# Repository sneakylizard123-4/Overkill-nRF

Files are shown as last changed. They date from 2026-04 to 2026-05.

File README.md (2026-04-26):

# Overkill nRF Board

A modular RF communication board designed for the **Overkill system**, built around the **nRF24L01+ radio module** instead of a bare RF IC + Amplifier. This makes the design easier to assemble, debug, and iterate while keeping it fully modular inside the Overkill ecosystem.

---

## Overview

The Overkill nRF Board handles wireless communication for the system using **nRF24L01+ modules**.

It is designed to be:

- Easy to assemble (no RF IC routing complexity)
- Modular (plugs into Overkill ecosystem)
- Hackable (all signals exposed)
- Repairable (no fine-pitch RF ICs)
- Hand-solderable (mostly 0805 components)

### Operating Modes

- **Standalone mode** → acts like a standard nRF24 breakout module
- **Integrated mode** → RF subsystem inside Overkill system

---

## Why

- Most off-the-shelf nRF24 setups are either too barebones or too messy to integrate into real projects. Debugging is hard, power handling is often ignored, and the RF design is usually not optimized for real-world use.
- This board is designed to be a **usable, hackable, and modular RF subsystem** that can be easily integrated into the Overkill system or used standalone for RF experimentation.

---

## Key Changes from Previous Revision

- Removed discrete nRF24 RF IC design
- Switched to **nRF24L01+ module-based design**
- Simplified RF routing significantly
- Improved reliability and build speed
- Reduced RF design complexity

---

## Hardware

### Radio

- nRF24L01+ module (SPI interface)
- Optional PA+LNA module support (with proper power handling)

### Components

- Mostly **0805 footprint components**
  - Easier soldering
  - Better availability
  - More forgiving for hand assembly

### Interface

Connection to Overkill system via **JST-PH connector**:

- 3.3V power
- Data signals

---

## Design Philosophy

This board prioritizes:

- Simplicity over compact size
- Modularity over integration
- Debuggability over RF perfection

The goal is fast iteration for RF experimentation inside the Overkill platform.

---

## Power Notes

- Requires stable **3.3V supply** or **USB power** with proper regulation
- nRF24 modules are 5V tolerant, but the esp32 is not, so 3.3V is used for the logic part of the board
- Add decoupling capacitors close to module
- PA+LNA modules may require higher current bursts during transmission, so ensure power supply can handle it

---

## PCB Design Notes

- Designed around **0805 components**
- Maintain solid ground plane under RF section
- Keep antenna area free of copper and components
- use external antennas if possible for better performance

---

## Images

All pictures and screenshots should be in the `images/` folder.

### PCB Layout

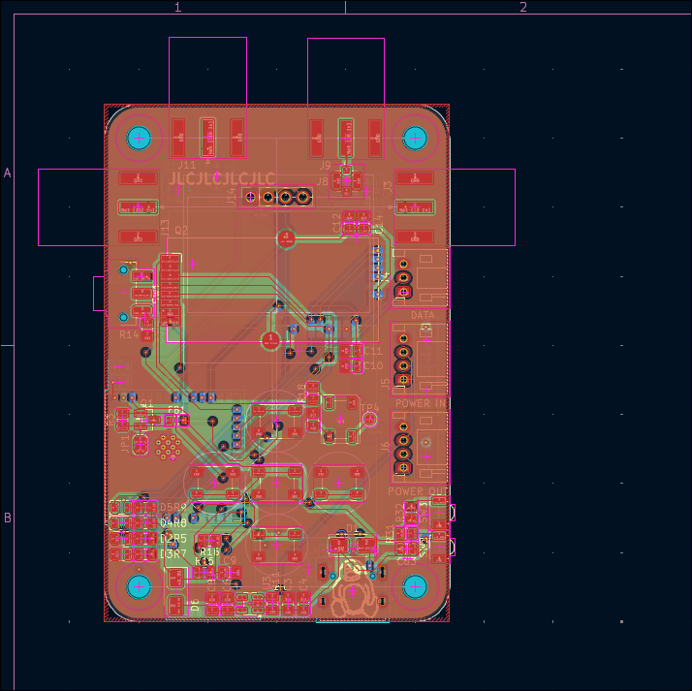
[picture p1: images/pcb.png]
PCB Layout


---

### 3D Renders

Top-side render (ray-traced KiCad):
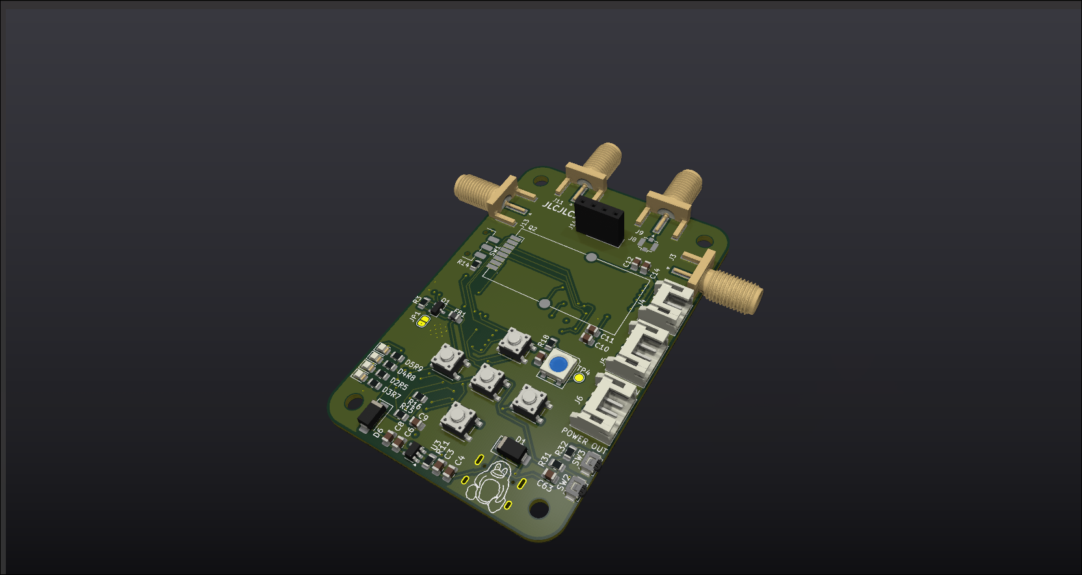
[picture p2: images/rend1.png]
Top Render


Bottom-side render (ray-traced KiCad):
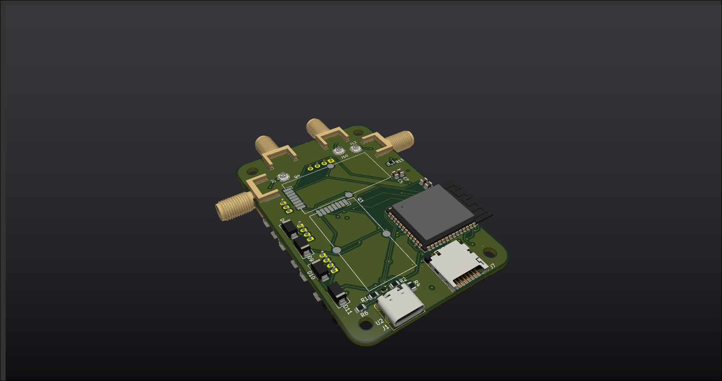
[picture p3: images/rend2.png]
Bottom Render


---

### Schematics

schematic sheet 1:
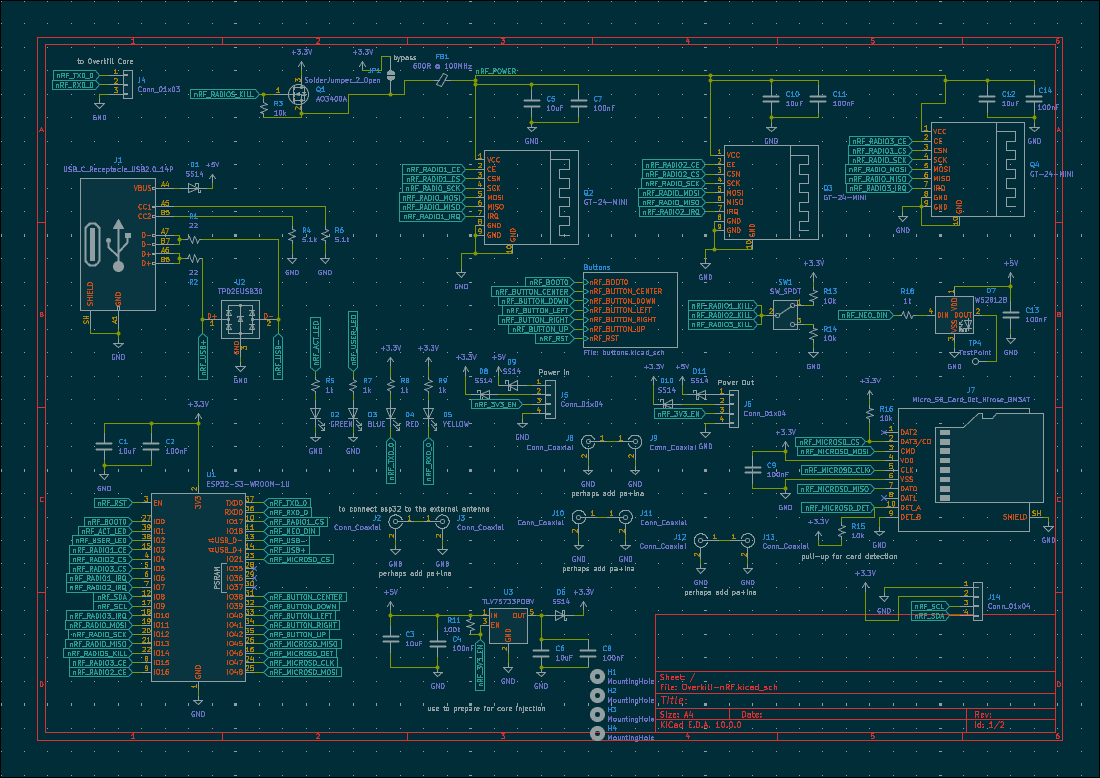
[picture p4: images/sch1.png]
Schematic 1


schematic sheet 2:
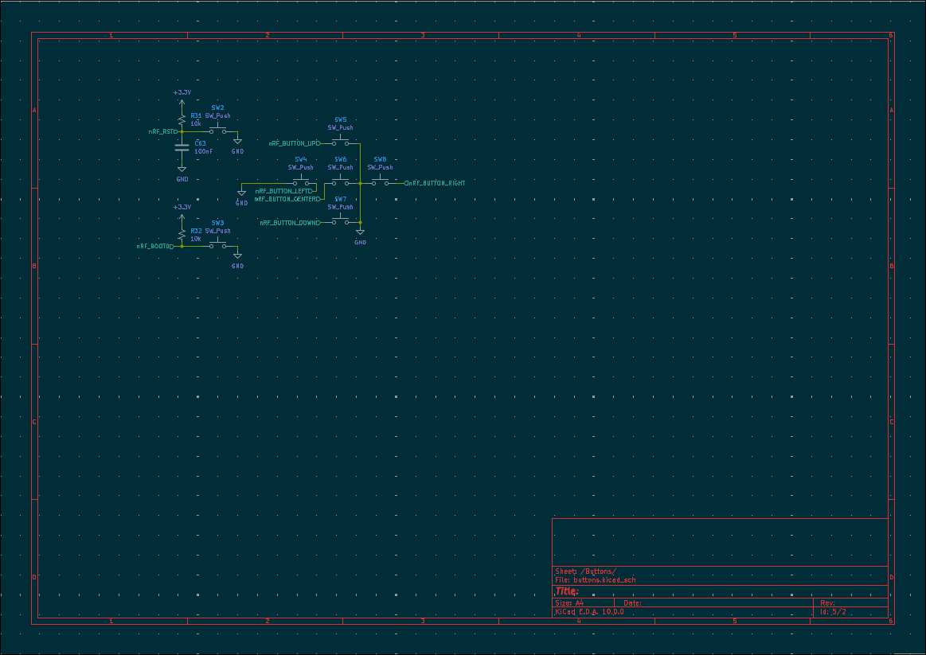
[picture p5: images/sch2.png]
Schematic 2


---

### Manufacturing / Sourcing

AliExpress cart:
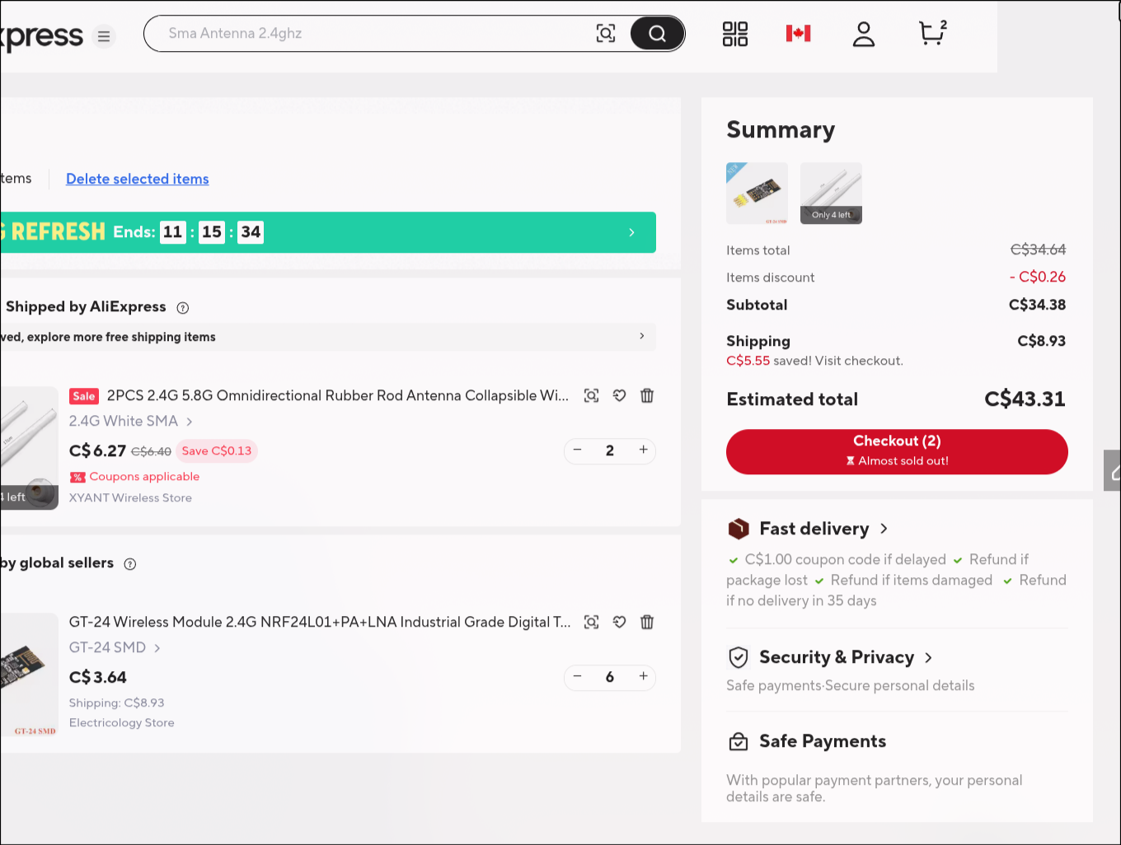
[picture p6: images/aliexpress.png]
AliExpress Cart


LCSC sourcing carts:
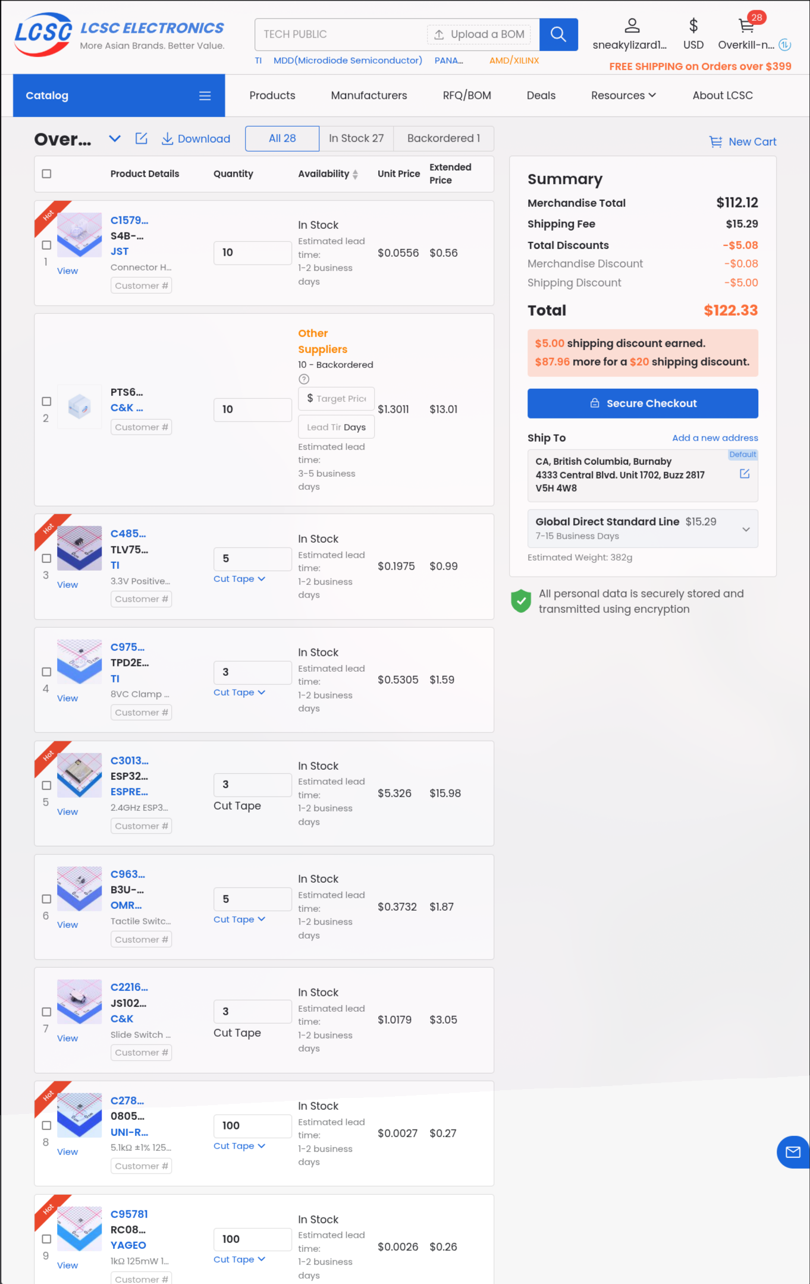
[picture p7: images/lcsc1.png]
LCSC Cart 1

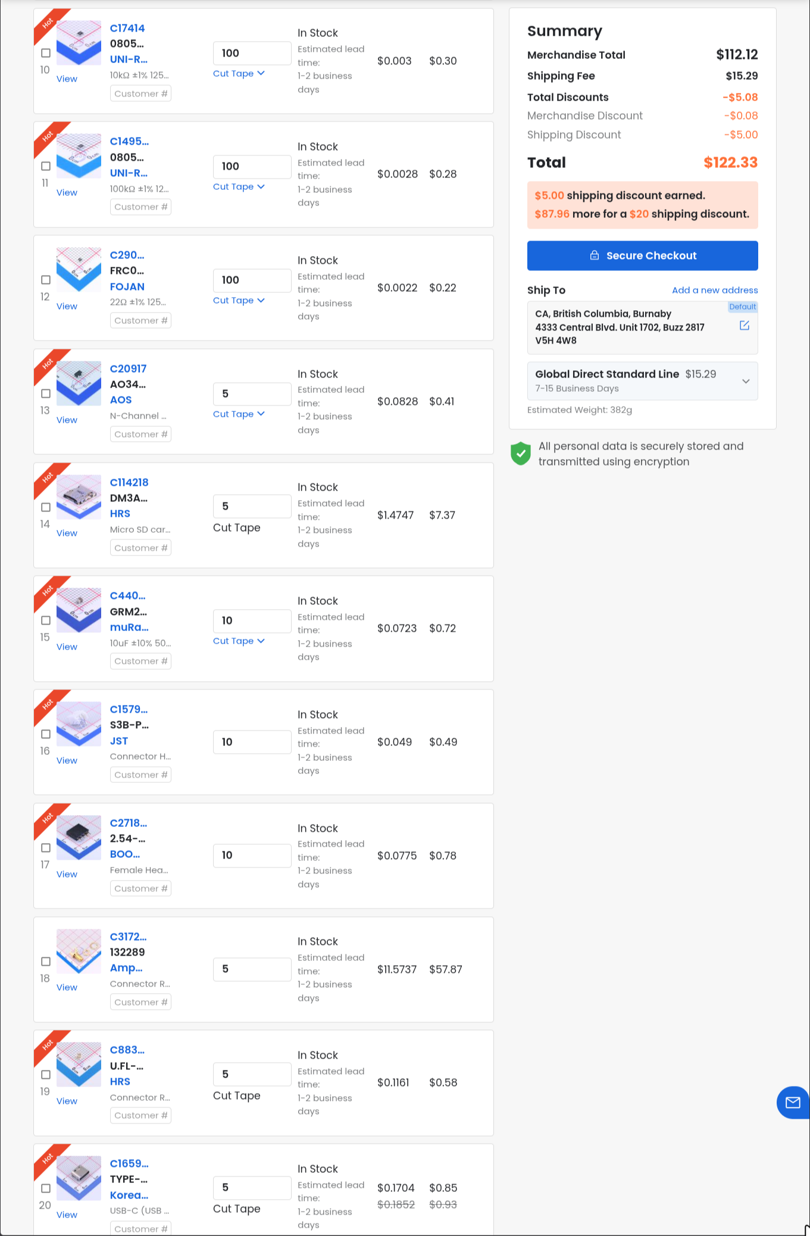
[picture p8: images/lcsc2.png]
LCSC Cart 2

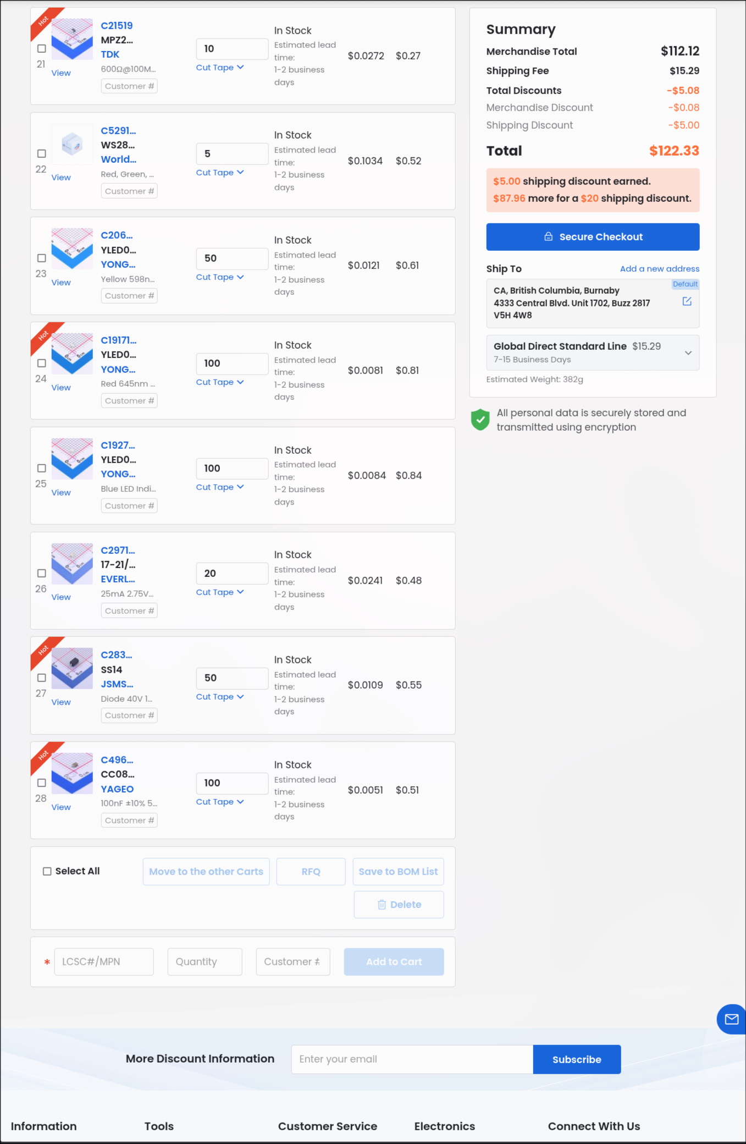
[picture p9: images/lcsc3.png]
LCSC Cart 3


JLCPCB cart:
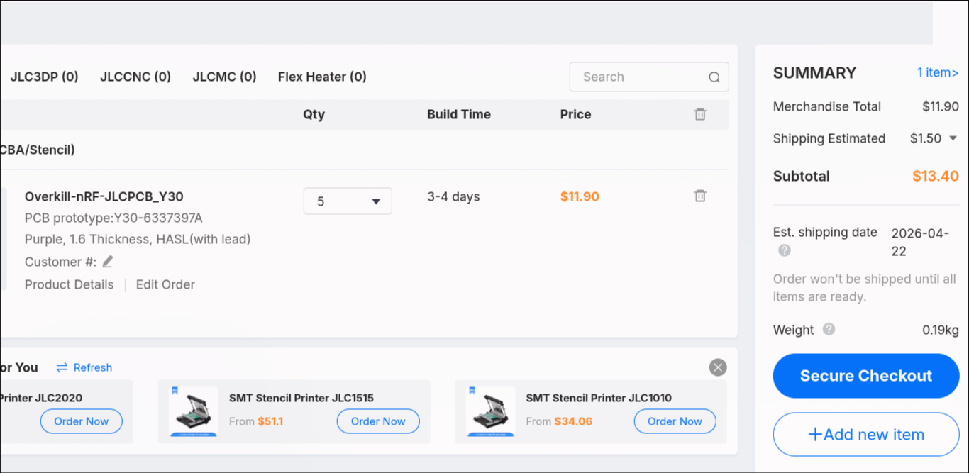
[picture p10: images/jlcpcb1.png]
JLCPCB Cart

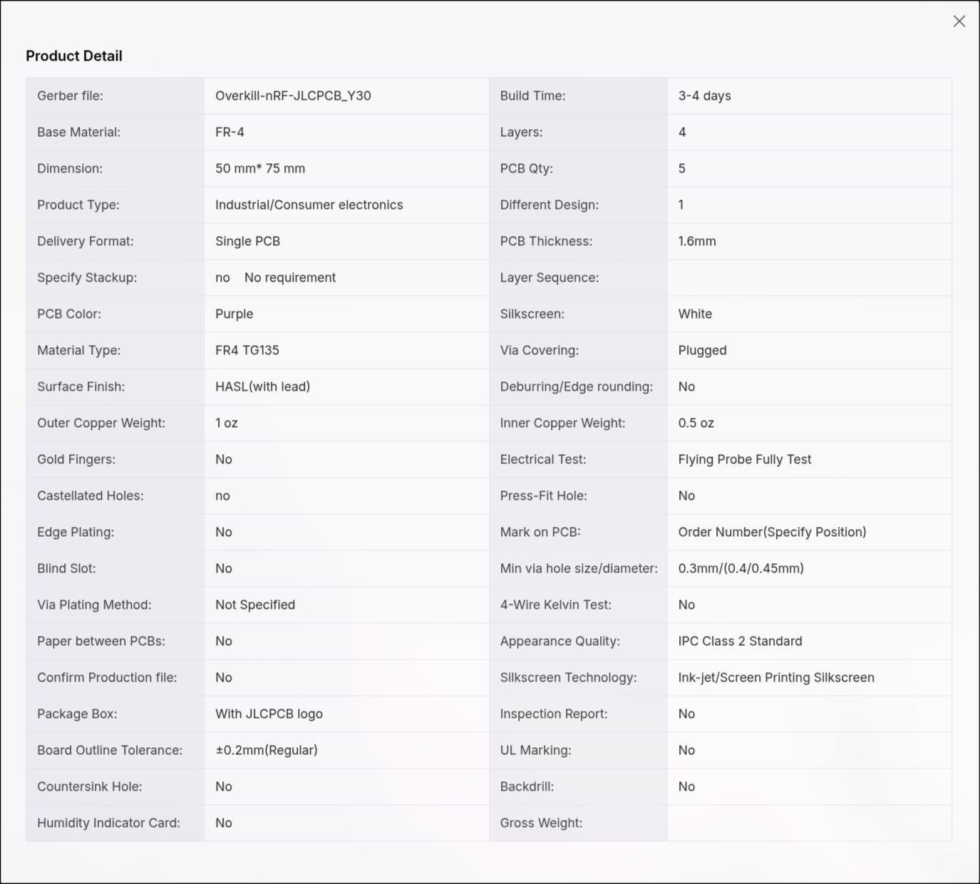
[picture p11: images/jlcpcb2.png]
JLCPCB Specs

or maybe PCBWay if they sponsor this project too!

---

### Zine Page
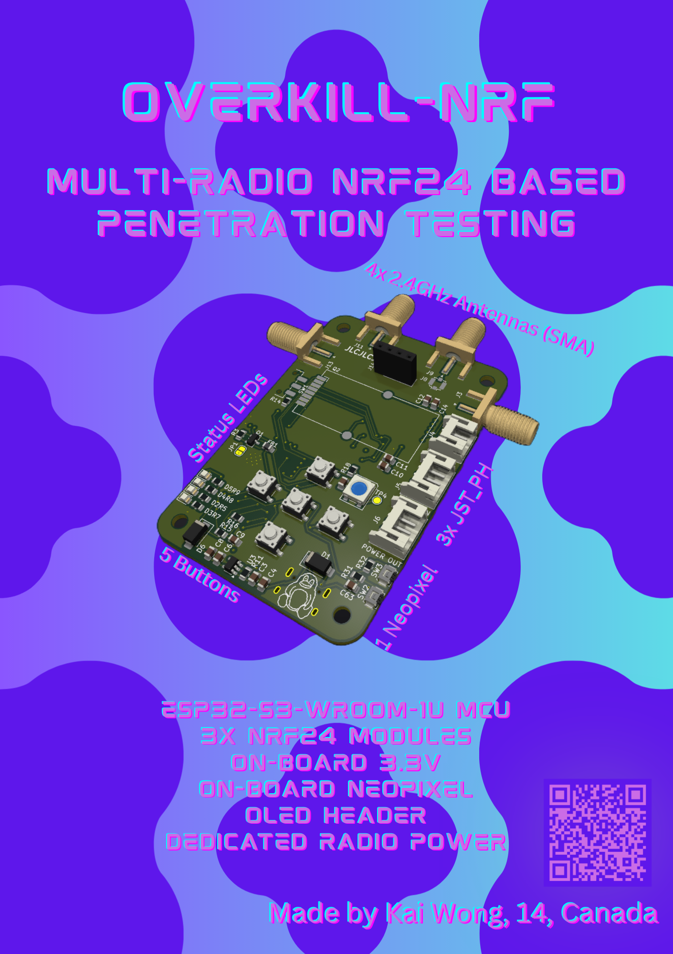
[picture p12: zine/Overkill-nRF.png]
Zine Page


## System Integration

The board connects into the Overkill system via JST-PH and is designed to interface with:

- Core controller board (SPI master)
- Power distribution board
- Other modular subsystems

Other parts of the system are being developed separately.

---

## Assembly and Programming

1. Start with passives
   - Solder resistors and capacitors first
   - Double-check values and placements
2. Power section
   - Assemble regulator and power filtering stage
   - Verify 3.3V rail before adding ICs
3. MCU and logic components
   - Solder ESP32 and other chips
   - Inspect for shorts between pins
4. nRF24 module
   - Carefully align pins
   - ensure solid ground connection
5. LEDs and indicators
   - Add status LEDs if desired
   - Match polarity correctly
   - Confirm resistor values for current limiting
6. Final inspection
   - Continuity check all power rails
   - Inspect RF sections for solder bridges

---

## How to Use

1. Powering the board
   - Connect USB power or 3.3V supply to the JST-PH connector
   - Ensure power supply can provide sufficient current for nRF24 module, especially if using PA+LNA version
2. Programming the ESP32
   - Use PlatformIO or Arduino IDE to flash firmware
   - Connect to the board via USB or UART for debugging
3. Integrating with Overkill system
   - Connect the board to the core controller via JST-PH
   - Use SPI interface to communicate with the nRF24 module
   - Test RF communication with other nRF24 devices

---

## Bill of Materials (BOM)

A full BOM is included in the repository.
see [bom.csv](bom/bom.csv) for details.

It includes:

- Component references
- Values / part numbers
- Quantities
- LCSC number
- Where to get them (AliExpress, LCSC, etc.)

---

## Repository Structure

- bom/ - Bill of Materials (BOM) files
- blender/ - 3D models and renders
- cad/ - STEP files
- firmware/ - code for project (platformio)
- images/ - pictures and screenshots
- kicad/ - KiCad project files
- zine/ - zine page for hack club

---

## Status

- Breadboard Prototype complete
- PCB routed in KiCad
- 3D assembly done
- Ready for fabrication

---

## Notes

This revision prioritizes usability and fast iteration over RF optimization complexity. The goal is to make RF experimentation inside the Overkill system fast, modular, and actually enjoyable to play with.

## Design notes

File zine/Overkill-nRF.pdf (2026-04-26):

# Overkill-nRF

## multi-radio nRF24 Based

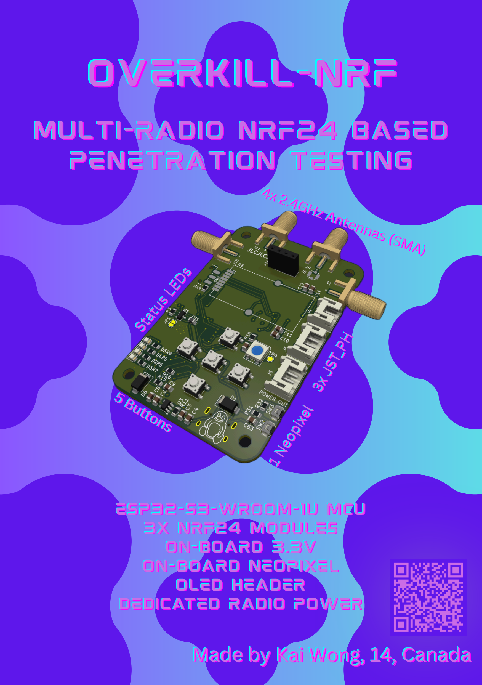
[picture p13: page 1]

ESP32-S3-WROOM-1U MCU 3x nRF24 Modules on-board 3.3v
on-board neopixel OLED header
Dedicated radio power

ESP32-S3-WROOM-1U MCU
3x nRF24 Modules
on-board 3.3v
on-board neopixel
OLED header
Dedicated radio power

## Penetration Testing

## multi-radio nRF24 Based Penetration Testing

3x JST_PH

## 4x 2.4GHz Antennas (SMA)

4x 2.

## ennas (SMA)

### Status LEDs

1 Neopixel el

## 5 Buttons

# Made by Kai Wong, 14, Canada

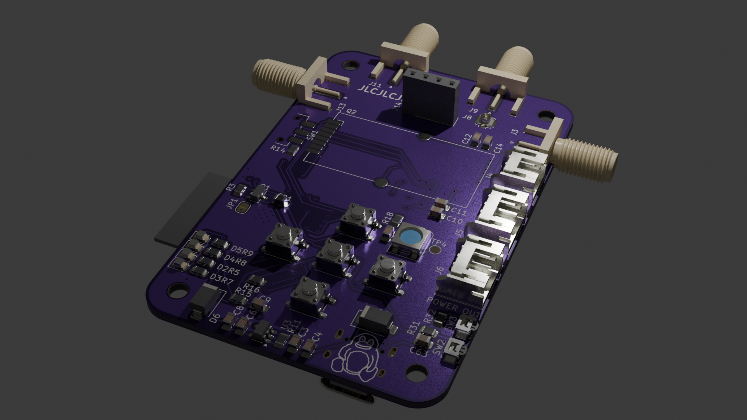
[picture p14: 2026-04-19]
blender/Purple.png

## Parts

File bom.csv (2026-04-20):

Category | Qty | Item | Description | Option/MPN | Manufacturer | Package | Unit Price | Total Price | Purchase Link
AliExpress | 2 | Antenna | 2.4GHz | 2.4 5.8G SMA | chinese | SMA connect | C$6.39 | C$12.78 | https://www.aliexpress.com/item/1005007573271319.html
AliExpress | 6 | Radio | nRF24L01+ | GT-24 SMD | nordic | SMA | C$3.64 | C$21.84 | https://www.aliexpress.com/item/4001134750735.html
AliExpress | 5 | Connector | SMA | female | amphenol | smd | C$5.91 | C$29.55 | https://www.aliexpress.com/item/1005007542020934.html
LCSC | 10 | Connector Header | 4 position 2mm Pitch | S4B-PH-K-S(LF)(SN) | JST | Through Hole Right Angle | 0.0556 | 0.56 | https://www.lcsc.com/product-detail/C157926.html
LCSC | 10 | Tactile Switch | SPST-NO 100gf | PTS647SN50SMTR2LFS | C&K | SMD | 1.3011 | 13.01 | https://www.lcsc.com/product-detail/C2799414.html
LCSC | 3 | ESD Diode | 8VC Clamp 5A | TPD2EUSB30DRTR | TI | SOT(9x3) | 0.5305 | 1.59 | https://www.lcsc.com/product-detail/C97502.html
LCSC | 3 | ESP32 Module | ESP32-S3-WROOM-1U-N16R8 | ESP32-S3-WROOM-1U-N16R8 | ESPRESSIF | SMD 19.2x18mm | 5.3260 | 15.98 | https://www.lcsc.com/product-detail/C3013946.html
LCSC | 5 | Tactile Switch | SPST 1.59N | B3U-3000P | OMRON | SMD 3x2.5mm | 0.3732 | 1.87 | https://www.lcsc.com/product-detail/C963349.html
LCSC | 3 | Slide Switch | SPDT 300mA | JS102011SAQN | C&K | SMD | 1.0179 | 3.05 | https://www.lcsc.com/product-detail/C221660.html
LCSC | 100 | Resistor | 5.1kΩ | 0805W8F5101T5E | UNI-ROYAL | 0805 | 0.0027 | 0.27 | https://www.lcsc.com/product-detail/C27834.html
LCSC | 100 | Resistor | 1kΩ | RC0805FR-071KL | YAGEO | 0805 | 0.0026 | 0.26 | https://www.lcsc.com/product-detail/C95781.html
LCSC | 100 | Resistor | 10kΩ | 0805W8F1002T5E | UNI-ROYAL | 0805 | 0.0030 | 0.30 | https://www.lcsc.com/product-detail/C17414.html
LCSC | 100 | Resistor | 100kΩ | 0805W8F1003T5E | UNI-ROYAL | 0805 | 0.0028 | 0.28 | https://www.lcsc.com/product-detail/C149504.html
LCSC | 100 | Resistor | 22Ω | FRC0805F22R0TS | FOJAN | 0805 | 0.0022 | 0.22 | https://www.lcsc.com/product-detail/C2907244.html
LCSC | 5 | MOSFET | N-Channel 30V | AO3400A | AOS | SOT-23 | 0.0828 | 0.41 | https://www.lcsc.com/product-detail/C20917.html
LCSC | 5 | Micro SD Connector | Push-Push | DM3AT-SF-PEJM5 | HRS | SMD | 1.4747 | 7.37 | https://www.lcsc.com/product-detail/C114218.html
LCSC | 10 | Capacitor | 10uF 50V | GRM21BR61H106KE43L | muRata | 0805 | 0.0723 | 0.72 | https://www.lcsc.com/product-detail/C440198.html
LCSC | 10 | Connector Header | 3 position 2mm | S3B-PH-K-S(LF)(SN) | JST | Through Hole Right Angle | 0.0490 | 0.49 | https://www.lcsc.com/product-detail/C157929.html
LCSC | 10 | Female Header | 4P 2.54mm | 2.54-1*4P | BOOMELE | Through Hole | 0.0775 | 0.78 | https://www.lcsc.com/product-detail/C2718488.html
LCSC | 5 | U.FL Connector | 50Ω | U.FL-R-SMT-1(80) | HRS | SMD | 0.1161 | 0.58 | https://www.lcsc.com/product-detail/C88374.html
LCSC | 5 | USB-C Connector | 16P | TYPE-C-31-M-12 | Hroparts | SMD | 0.1704 | 0.85 | https://www.lcsc.com/product-detail/C165948.html
LCSC | 10 | Ferrite Bead | 600Ω@100MHz | MPZ2012S601AT000 | TDK | 0805 | 0.0272 | 0.27 | https://www.lcsc.com/product-detail/C21519.html
LCSC | 5 | RGB LED | WS2812B-V6 | WS2812B-V6 | Worldsemi | SMD5050 | 0.1034 | 0.52 | https://www.lcsc.com/product-detail/C52917433.html
LCSC | 50 | LED | Yellow 598nm | YLED0805Y | YONGYUTAI | 0805 | 0.0121 | 0.61 | https://www.lcsc.com/product-detail/C20608785.html
LCSC | 100 | LED | Red 645nm | YLED0805R | YONGYUTAI | 0805 | 0.0081 | 0.81 | https://www.lcsc.com/product-detail/C19171391.html
LCSC | 100 | LED | Blue | YLED0805B | YONGYUTAI | 0805 | 0.0084 | 0.84 | https://www.lcsc.com/product-detail/C19273154.html
LCSC | 20 | LED | Green 518nm | 17-21/GHC-XS1T2M/4T | EVERLIGHT | 0805 | 0.0241 | 0.48 | https://www.lcsc.com/product-detail/C2971978.html
LCSC | 50 | Diode | 40V 1A | SS14 | JSMSEMI | SMA | 0.0109 | 0.55 | https://www.lcsc.com/product-detail/C2837270.html
LCSC | 100 | Capacitor | 100nF 50V | CC0805KRX7R9BB104 | YAGEO | 0805 | 0.0051 | 0.51 | https://www.lcsc.com/product-detail/C49678.html

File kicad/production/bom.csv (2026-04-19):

Designator | Footprint | Quantity | Value | LCSC Part #
C1, C10, C12, C3, C5, C6 | 0805 | 6 | 10uF
C11, C13, C14, C2, C4, C63, C7, C8, C9 | 0805 | 9 | 100nF
D1, D10, D11, D6, D8, D9 | D_SMA | 6 | SS14
D2 | 0805 | 1 | GREEN
D3 | 0805 | 1 | BLUE
D4 | 0805 | 1 | RED
D5 | 0805 | 1 | YELLOW
D7 | LED_WS2812B_PLCC4_5.0x5.0mm_P3.2mm | 1 | WS2812B
FB1 | 0805 | 1 | 600R @ 100MHz
J1 | USB_C_Receptacle_HRO_TYPE-C-31-M-12 | 1 | USB_C_Receptacle_USB2.0_14P
J10, J12, J2, J8 | U.FL_Molex_MCRF_73412-0110_Vertical | 4 | Conn_Coaxial
J11, J13, J3, J9 | SMA_Amphenol_132289_EdgeMount | 4 | Conn_Coaxial
J14 | PinSocket_1x04_P2.54mm_Vertical | 1 | Conn_01x04
J4 | JST_PH_S3B-PH-K_1x03_P2.00mm_Horizontal | 1 | Conn_01x03
J5, J6 | JST_PH_S4B-PH-K_1x04_P2.00mm_Horizontal | 2 | Conn_01x04
J7 | microSD_HC_Molex_104031-0811 | 1 | Micro_SD_Card_Det_Hirose_DM3AT
Q1 | SOT-23 | 1 | AO3400A
Q2, Q3, Q4 | nRF24L01-GT24_Breakout | 3 | GT-24-MINI
R1, R2 | 0805 | 2 | 22
R11 | 0805 | 1 | 100k
R13, R14, R15, R16, R3, R31, R32 | 0805 | 7 | 10k
R18, R5, R7, R8, R9 | 0805 | 5 | 1k
R4, R6 | 0805 | 2 | 5.1k
SW1 | SW_SPDT_CK_JS102011SAQN | 1 | SW_SPDT
SW2, SW3 | SW_SPST_B3U-3000P | 2 | SW_Push
SW4, SW5, SW6, SW7, SW8 | SW_SPST_PTS647_Sx38 | 5 | SW_Push
TP4 | TestPoint_Pad_D1.5mm | 1 | TestPoint
U1 | ESP32-S3-WROOM-1U | 1 | ESP32-S3-WROOM-1U
U2 | Texas_DRT-3 | 1 | TPD2EUSB30
U3 | SOT-23-5 | 1 | TLV75733PDBV

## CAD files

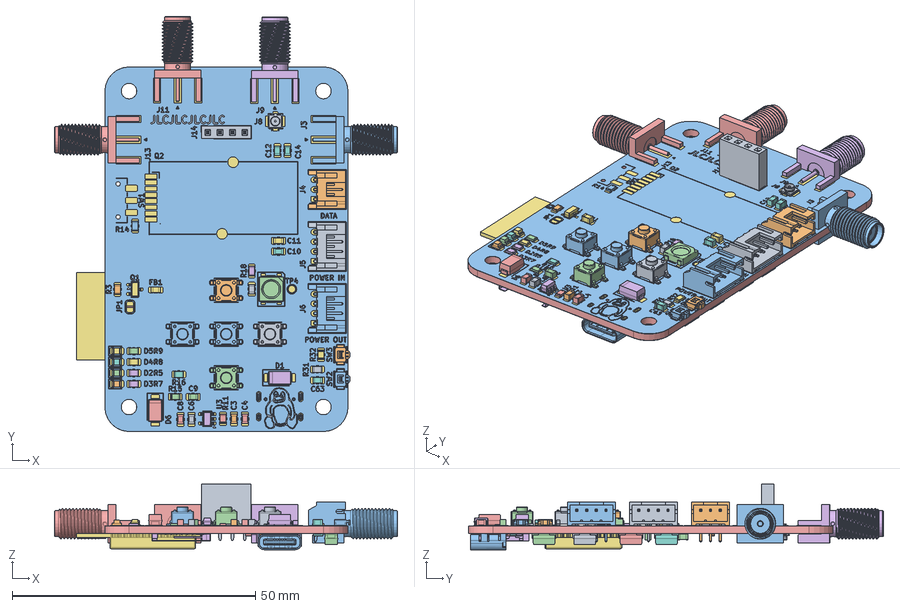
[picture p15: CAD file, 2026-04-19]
cad/Overkill-nRF.FCStd
70.6 x 85.4 x 13.5 mm
PinSocket_1x04_P2.54mm_Vertical
LED_0805_2012Metric
SMA_Amphenol_132289_EdgeMount
R_0805_2012Metric
C_0805_2012Metric
R_0805_2012Metric001
SOT-23
R_0805_2012Metric002
C_0805_2012Metric001
JST_PH_S3B-PH-K_1x03_P2.00mm_Horizontal
SW_SPST_B3U-3000P
SW_SPST_PTS647Sx38
SMA_Amphenol_132289_EdgeMount001
R_0805_2012Metric003
R_0805_2012Metric004
C_0805_2012Metric002
C_0805_2012Metric003
R_0805_2012Metric005
JST_PH_S4B-PH-K_1x04_P2.00mm_Horizontal
LED_WS2812B_PLCC4_5.0x5.0mm_P3.2mm
C_0805_2012Metric004
D_SMA
L_0805_2012Metric
C_0805_2012Metric005
U.FL_Hirose_U.FL-R-SMT-1_Vertical
SW_SPST_PTS647Sx039
SW_SPST_PTS647Sx040
C_0805_2012Metric006
D_SMA001
SOT-23-5
R_0805_2012Metric006
LED_0805_2012Metric001
R_0805_2012Metric007
SW_SPST_B3U-3000P001
SW_SPST_PTS647Sx041
LED_0805_2012Metric002
R_0805_2012Metric008
R_0805_2012Metric009
C_0805_2012Metric007
C_0805_2012Metric008
SW_SPST_PTS647Sx042
C_0805_2012Metric009
R_0805_2012Metric010
R_0805_2012Metric011
SMA_Amphenol_132289_EdgeMount002
SMA_Amphenol_132289_EdgeMount003
LED_0805_2012Metric003
C_0805_2012Metric010
JST_PH_S4B-PH-K_1x04_P2.00mm_Horizontal001
R_0805_2012Metric012
U.FL_Hirose_U.FL-R-SMT-1_Vertical001
D_SMA002
U.FL_Hirose_U.FL-R-SMT-1_Vertical002
microSD_HC_Hirose_DM3D-SF
C_0805_2012Metric011
D_SMA003
D_SMA004
Texas_DRT-3
C_0805_2012Metric012
C_0805_2012Metric013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

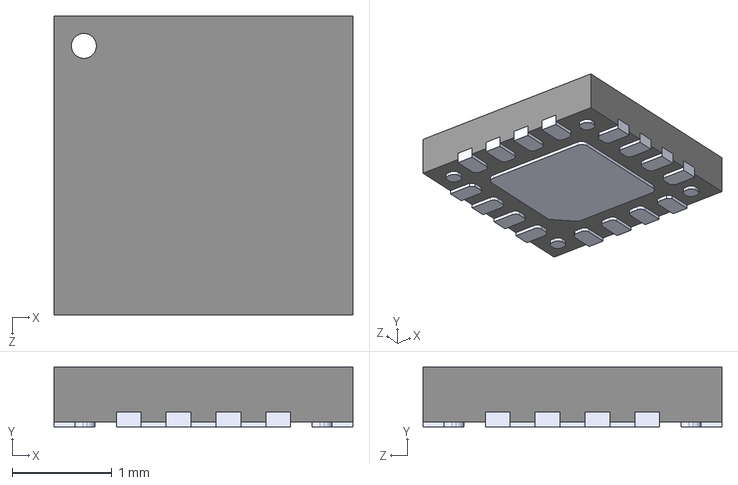
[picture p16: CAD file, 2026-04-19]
kicad/Overkill-nRF-Parts/RFX2401C/RFX2401C.step
3.00 x 0.6 x 3.00 mm

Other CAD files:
blender/Overkill-nRF.blend

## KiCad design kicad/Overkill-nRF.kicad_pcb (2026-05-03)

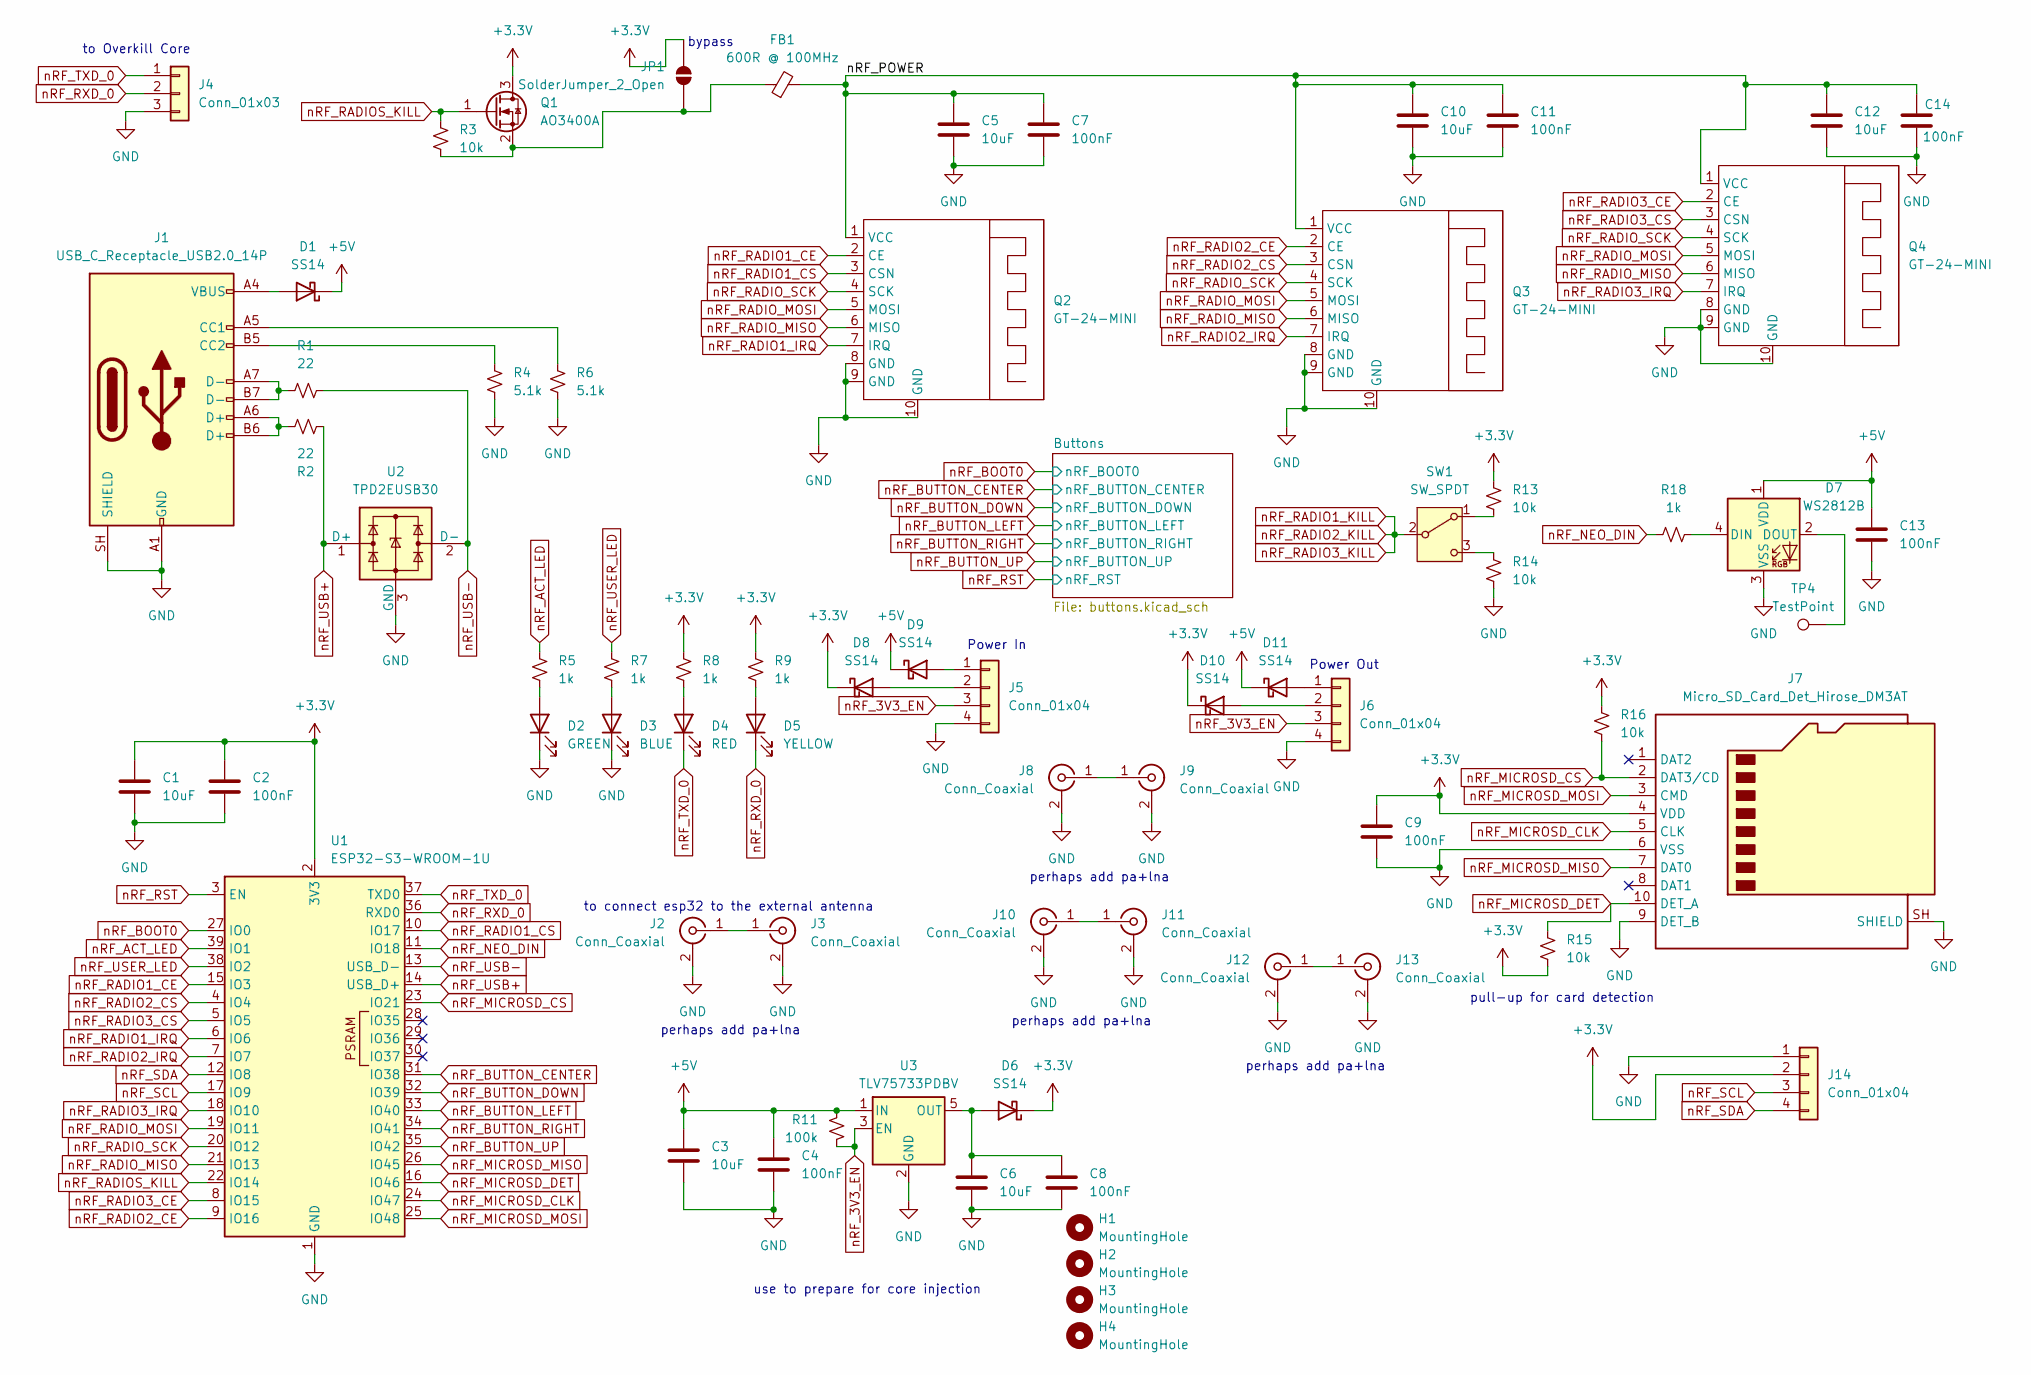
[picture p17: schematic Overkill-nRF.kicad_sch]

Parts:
C1, C3, C5, C6, C10, C12: 10uF; C_0805_2012Metric
C2, C4, C7, C8, C9, C11, C13, C14: 100nF; C_0805_2012Metric
D1, D6, D8, D9, D10, D11: SS14; D_SMA
D2: GREEN; LED_0805_2012Metric
D3: BLUE; LED_0805_2012Metric
D4: RED; LED_0805_2012Metric
D5: YELLOW; LED_0805_2012Metric
D7: WS2812B; LED_WS2812B_PLCC4_5.0x5.0mm_P3.2mm
FB1: 600R @ 100MHz; L_0805_2012Metric
H1, H2, H3, H4: MountingHole; MountingHole_3.2mm_M3
J1: USB_C_Receptacle_USB2.0_14P; USB_C_Receptacle_HRO_TYPE-C-31-M-12
J2, J8, J10, J12: Conn_Coaxial; U.FL_Molex_MCRF_73412-0110_Vertical
J3, J9, J11, J13: Conn_Coaxial; SMA_Amphenol_132289_EdgeMount
J4: Conn_01x03; JST_PH_S3B-PH-K_1x03_P2.00mm_Horizontal
J5, J6: Conn_01x04; JST_PH_S4B-PH-K_1x04_P2.00mm_Horizontal
J7: Micro_SD_Card_Det_Hirose_DM3AT; microSD_HC_Molex_104031-0811
J14: Conn_01x04; PinSocket_1x04_P2.54mm_Vertical
JP1: SolderJumper_2_Open; SolderJumper-2_P1.3mm_Open_RoundedPad1.0x1.5mm
Q1: AO3400A; SOT-23
Q2, Q3, Q4: GT-24-MINI; nRF24L01-GT24_Breakout
R1, R2: 22; R_0805_2012Metric
R3, R13, R14, R15, R16: 10k; R_0805_2012Metric
R4, R6: 5.1k; R_0805_2012Metric
R5, R7, R8, R9, R18: 1k; R_0805_2012Metric
R11: 100k; R_0805_2012Metric
SW1: SW_SPDT; SW_SPDT_CK_JS102011SAQN
TP4: TestPoint; TestPoint_Pad_D1.5mm
U1: ESP32-S3-WROOM-1U
U2: TPD2EUSB30; Texas_DRT-3
U3: TLV75733PDBV; SOT-23-5

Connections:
+3.3V: C1.1, C2.1, C9.1, D6.1 (K), D8.1 (K), D10.1 (K), J7.4 (VDD), J14.2, JP1.2 (B), Q1.3 (D), R8.1, R9.1, R13.1, R15.2, R16.1, U1.2 (3V3); also elsewhere on the board
+5V: C3.1, C4.1, C13.1, D1.1 (K), D7.1 (VDD), D9.1 (K), D11.1 (K), R11.1, U3.1 (IN)
/nRF_POWER: C5.1, C7.1, C10.1, C11.1, C12.1, C14.1, FB1.2, Q2.1 (VCC), Q3.1 (VCC), Q4.1 (VCC)
GND: C1.2, C2.2, C3.2, C4.2, C5.2, C6.2, C7.2, C8.2, C9.2, C10.2, C11.2, C12.2, C13.2, C14.2, D2.1 (K), D3.1 (K), D7.3 (VSS), J1.A1 (GND), J1.A12 (GND), J1.B1 (GND), J1.B12 (GND), J1.SH (SHIELD), J2.2 (Ext), J3.2 (Ext), J4.3, J5.4, J6.4, J7.6 (VSS), J7.9 (DET_B), J7.SH (SHIELD), J8.2 (Ext), J9.2 (Ext), J10.2 (Ext), J11.2 (Ext), J12.2 (Ext), J13.2 (Ext), J14.1, Q2.8 (GND), Q2.9 (GND), Q2.10 (GND), Q3.8 (GND), Q3.9 (GND), Q3.10 (GND), Q4.8 (GND), Q4.9 (GND), Q4.10 (GND), R4.2, R6.2, R14.2, U1.1 (GND), U1.40 (GND), U1.41 (GND), U2.3 (GND), U3.2 (GND); also elsewhere on the board
unnamed: D1.2 (A), J1.A4 (VBUS), J1.A9 (VBUS), J1.B4 (VBUS), J1.B9 (VBUS)
unnamed: D2.2 (A), R5.2
unnamed: D3.2 (A), R7.2
unnamed: D4.2 (A), R8.2
unnamed: D5.2 (A), R9.2
unnamed: C6.1, C8.1, D6.2 (A), U3.5 (OUT)
unnamed: D7.4 (DIN), R18.2
unnamed: D7.2 (DOUT), TP4.1 (1_1)
unnamed: D8.2 (A), J5.2
unnamed: D9.2 (A), J5.1
unnamed: D10.2 (A), J6.2
unnamed: D11.2 (A), J6.1
unnamed: J1.A5 (CC1), R6.1
unnamed: J1.B5 (CC2), R4.1
unnamed: J1.A6 (D+), J1.B6 (D+), R2.2
unnamed: J1.A7 (D-), J1.B7 (D-), R1.1
unnamed: J2.1 (In), J3.1 (In)
unnamed: J8.1 (In), J9.1 (In)
unnamed: J10.1 (In), J11.1 (In)
unnamed: J12.1 (In), J13.1 (In)
unnamed: FB1.1, JP1.1 (A), Q1.2 (S), R3.2
unnamed: R13.2, SW1.1 (A)
unnamed: R14.1, SW1.3 (C)
nRF_3V3_EN: J5.3, J6.3, R11.2, U3.3 (EN)
nRF_ACT_LED: R5.1, U1.39 (IO1)
nRF_BOOT0: U1.27 (IO0); also elsewhere on the board
nRF_BUTTON_CENTER: U1.31 (IO38); also elsewhere on the board
nRF_BUTTON_DOWN: U1.32 (IO39); also elsewhere on the board
nRF_BUTTON_LEFT: U1.33 (IO40); also elsewhere on the board
nRF_BUTTON_RIGHT: U1.34 (IO41); also elsewhere on the board
nRF_BUTTON_UP: U1.35 (IO42); also elsewhere on the board
nRF_MICROSD_CLK: J7.5 (CLK), U1.24 (IO47)
nRF_MICROSD_CS: J7.2 (DAT3/CD), R16.2, U1.23 (IO21)
nRF_MICROSD_DET: J7.10 (DET_A), R15.1, U1.16 (IO46)
nRF_MICROSD_MISO: J7.7 (DAT0), U1.26 (IO45)
nRF_MICROSD_MOSI: J7.3 (CMD), U1.25 (IO48)
nRF_NEO_DIN: R18.1, U1.11 (IO18)
nRF_RADIO1_CE: Q2.2 (CE), U1.15 (IO3)
nRF_RADIO1_CS: Q2.3 (CSN), U1.10 (IO17)
nRF_RADIO1_IRQ: Q2.7 (IRQ), U1.6 (IO6)
nRF_RADIO1_KILL: SW1.2 (B)
nRF_RADIO2_CE: Q3.2 (CE), U1.9 (IO16)
nRF_RADIO2_CS: Q3.3 (CSN), U1.4 (IO4)
nRF_RADIO2_IRQ: Q3.7 (IRQ), U1.7 (IO7)
nRF_RADIO3_CE: Q4.2 (CE), U1.8 (IO15)
nRF_RADIO3_CS: Q4.3 (CSN), U1.5 (IO5)
nRF_RADIO3_IRQ: Q4.7 (IRQ), U1.18 (IO10)
nRF_RADIOS_KILL: Q1.1 (G), R3.1, U1.22 (IO14)
nRF_RADIO_MISO: Q2.6 (MISO), Q3.6 (MISO), Q4.6 (MISO), U1.21 (IO13)
nRF_RADIO_MOSI: Q2.5 (MOSI), Q3.5 (MOSI), Q4.5 (MOSI), U1.19 (IO11)
nRF_RADIO_SCK: Q2.4 (SCK), Q3.4 (SCK), Q4.4 (SCK), U1.20 (IO12)
nRF_RST: U1.3 (EN); also elsewhere on the board
nRF_RXD_0: D5.1 (K), J4.2, U1.36 (RXD0)
nRF_SCL: J14.3, U1.17 (IO9)
nRF_SDA: J14.4, U1.12 (IO8)
nRF_TXD_0: D4.1 (K), J4.1, U1.37 (TXD0)
nRF_USB+: R2.1, U1.14 (USB_D+), U2.1 (D+)
nRF_USB-: R1.2, U1.13 (USB_D-), U2.2 (D-)
nRF_USER_LED: R7.1, U1.38 (IO2)

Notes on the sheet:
pull-up for card detection
perhaps add pa+lna
to connect esp32 to the external antenna
bypass
Power In
Power Out
to Overkill Core
use to prepare for core injection

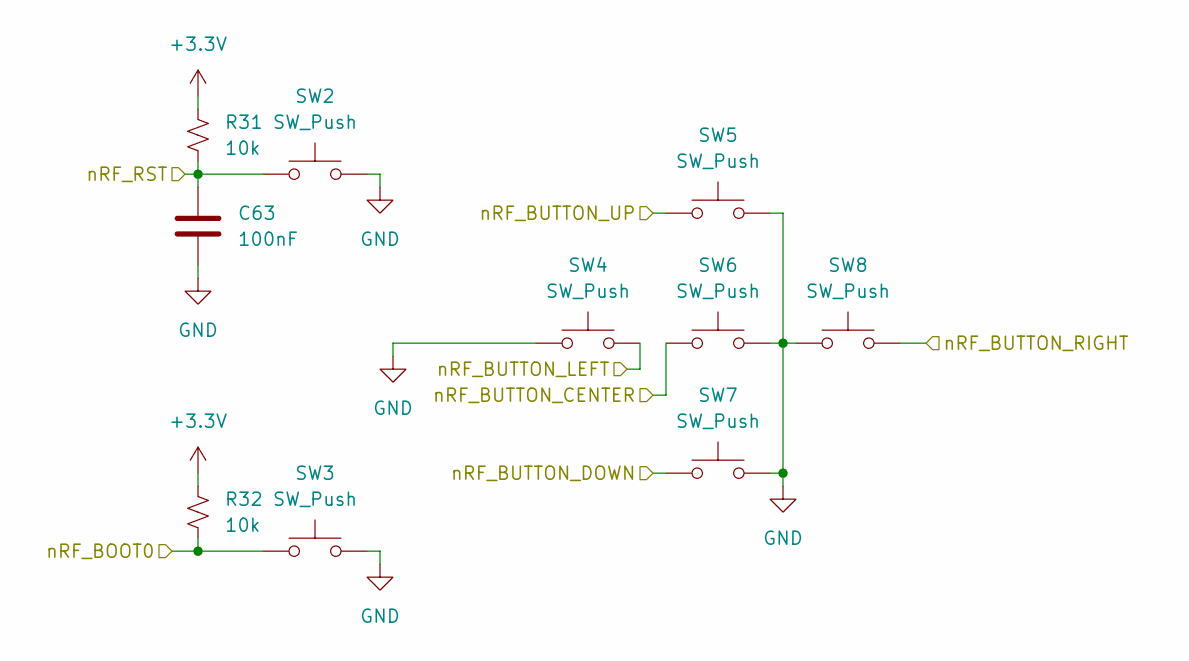
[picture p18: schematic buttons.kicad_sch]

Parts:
C63: 100nF; C_0805_2012Metric
R31, R32: 10k; R_0805_2012Metric
SW2, SW3: SW_Push; SW_SPST_B3U-3000P
SW4, SW5, SW6, SW7, SW8: SW_Push; SW_SPST_PTS647_Sx38

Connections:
+3.3V: R31.1, R32.1; also elsewhere on the board
GND: C63.2, SW2.2, SW3.2, SW4.1, SW5.2, SW6.2, SW7.2, SW8.1; also elsewhere on the board
nRF_BOOT0: R32.2, SW3.1; also elsewhere on the board
nRF_BUTTON_CENTER: SW6.1; also elsewhere on the board
nRF_BUTTON_DOWN: SW7.1; also elsewhere on the board
nRF_BUTTON_LEFT: SW4.2; also elsewhere on the board
nRF_BUTTON_RIGHT: SW8.2; also elsewhere on the board
nRF_BUTTON_UP: SW5.1; also elsewhere on the board
nRF_RST: C63.1, R31.2, SW2.1; also elsewhere on the board

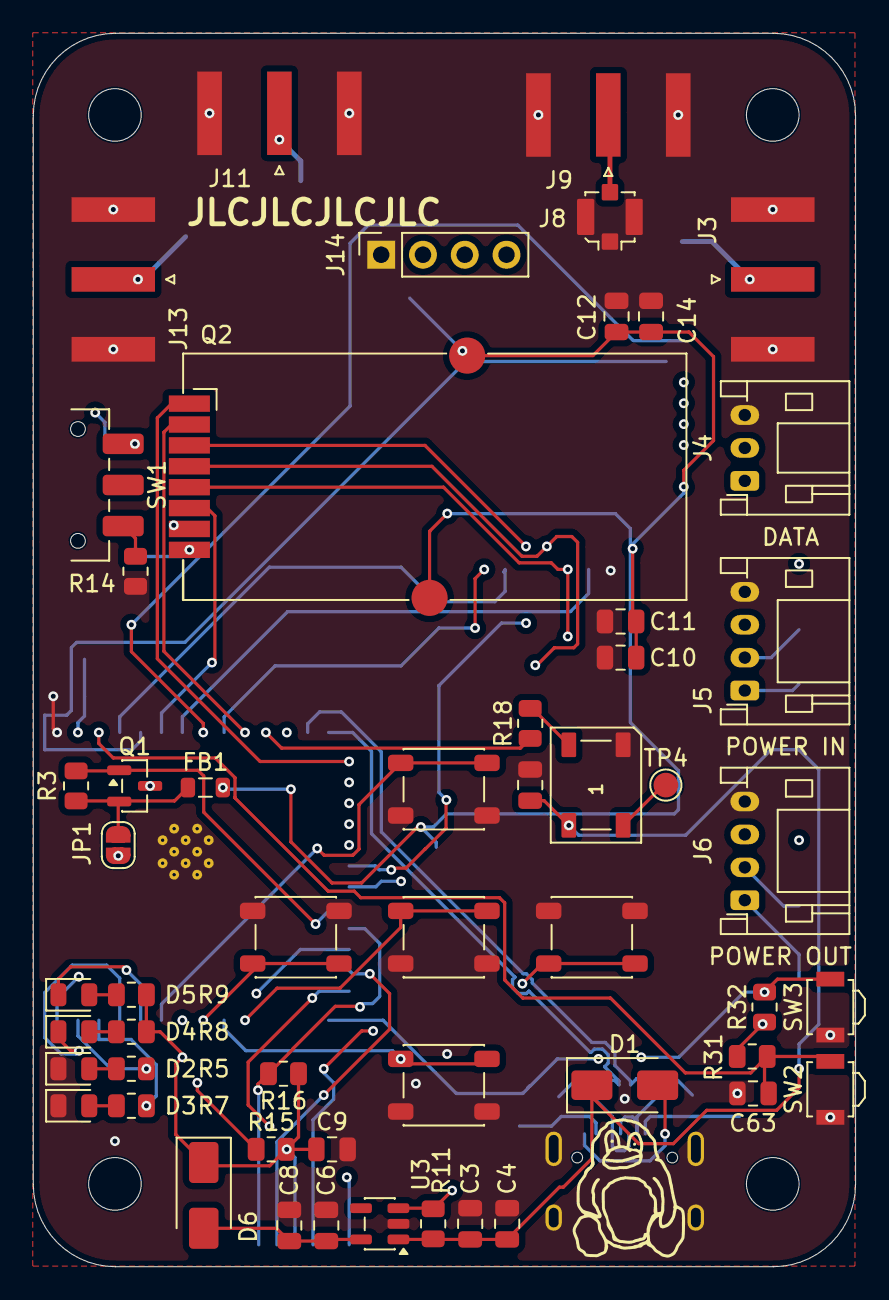
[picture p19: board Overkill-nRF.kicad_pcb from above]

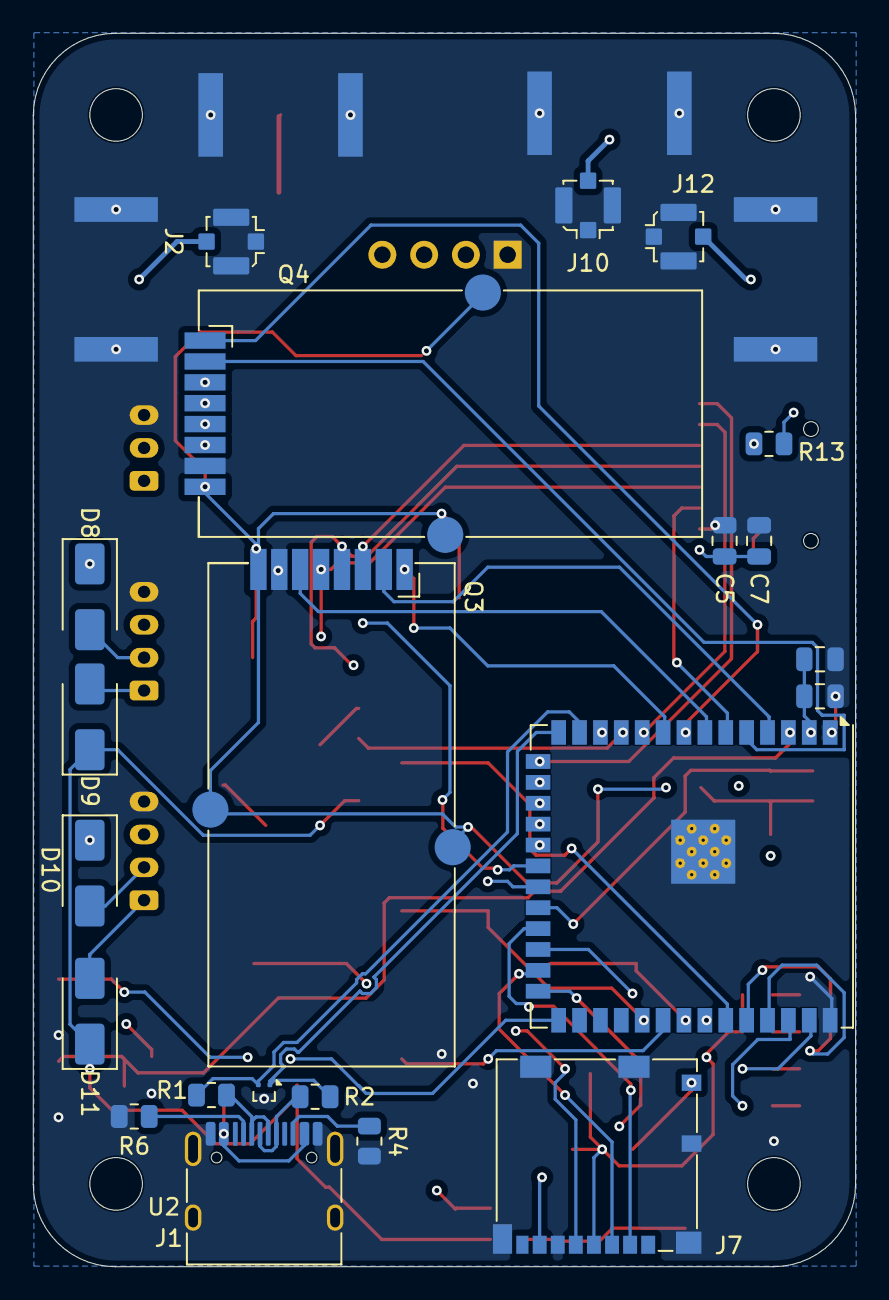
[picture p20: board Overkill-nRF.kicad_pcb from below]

Board: 4 copper layers, 50.0 x 75.0 mm, 79 parts (22 on the bottom side), 62 nets.

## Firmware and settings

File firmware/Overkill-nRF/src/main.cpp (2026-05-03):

/* ____________________________
   This software is licensed under the MIT License:
   https://github.com/cifertech/nrfbox
   ________________________________________ */

#include "icon.h"
#include "setting.h"
#include "config.h"

extern uint8_t oledBrightness;

const int NUM_ITEMS = 12;
const int MAX_ITEM_LENGTH = 20;

const unsigned char* bitmap_icons[NUM_ITEMS] = {
  bitmap_icon_scanner, bitmap_icon_analyzer, bitmap_icon_jammer, bitmap_icon_kill,
  bitmap_icon_ble_jammer, bitmap_icon_spoofer, bitmap_icon_apple, bitmap_icon_ble,
  bitmap_icon_wifi, bitmap_icon_wifi_jammer, bitmap_icon_about, 
  bitmap_icon_setting
};

char menu_items[NUM_ITEMS][MAX_ITEM_LENGTH] = {  
  "Scanner", "Analyzer", "WLAN Jammer", "Proto Kill", "BLE Jammer",
  "BLE Spoofer", "Sour Apple", "BLE Scan", "WiFi Scan", 
  "Deauther", "About", "Setting"
};

void (*menu_functions[NUM_ITEMS])() = {
  Scanner::scannerSetup, Analyzer::analyzerSetup, Jammer::jammerSetup,
  ProtoKill::blackoutSetup, BleJammer::blejammerSetup, Spoofer::spooferSetup,
  SourApple::sourappleSetup, BleScan::blescanSetup, WifiScan::wifiscanSetup, Deauther::deautherSetup,
  utils, Setting::settingSetup
};

void (*menu_loop_functions[NUM_ITEMS])() = {
  Scanner::scannerLoop, Analyzer::analyzerLoop, Jammer::jammerLoop,
  ProtoKill::blackoutLoop, BleJammer::blejammerLoop, Spoofer::spooferLoop,
  SourApple::sourappleLoop, BleScan::blescanLoop, WifiScan::wifiscanLoop, Deauther::deautherLoop,
  nullptr, Setting::settingLoop
};

int item_selected = 0;
int current_screen = 0;
unsigned long last_button_time = 0;
const unsigned long DEBOUNCE_DELAY = 150; 
const unsigned long POST_PRESS_DELAY = 200; 
                
void drawMenu() {
  u8g2.clearBuffer();
  if (current_screen != 0) return;

  u8g2.setFont(u8g2_font_5x7_tf); 
  u8g2.drawBox(0, 0, 128, 8); 
  u8g2.setDrawColor(0); 
  char versionStr[16];
  for (size_t i = 0; i < sizeof(txt_v); i++) {
    versionStr[i] = (char)txt_v[i];
  }
  versionStr[sizeof(txt_v)] = '\0';

  u8g2.setDrawColor(0);

  Str(2, 7, txt_n, sizeof(txt_n));
  int version_width = u8g2.getUTF8Width(versionStr);
  Str(128 - version_width - 2, 7, txt_v, sizeof(txt_v));
  u8g2.setDrawColor(1); 
  u8g2.drawHLine(0, 8, 128); 

  const int icons_per_row = 3;
  const int icons_per_col = 2;
  const int max_display_items = icons_per_row * icons_per_col; 

  int selected_col = item_selected % icons_per_row;
  int selected_row = (item_selected / icons_per_row) % icons_per_col;
  if (item_selected == 12) {
    selected_row = 1; 
  }
  int highlight_x = 13 + selected_col * 40;
  int highlight_y = 14 + selected_row * 24;

  int start_row = (item_selected / icons_per_row) - selected_row;
  if (start_row < 0) start_row = 0;
  int total_rows = (NUM_ITEMS + icons_per_row - 1) / icons_per_row;
  if (start_row > total_rows - icons_per_col) start_row = total_rows - icons_per_col;
  if (start_row < 0) start_row = 0; 
  int start_item = start_row * icons_per_row;
  int end_item = min(NUM_ITEMS, start_item + max_display_items);

  for (int i = start_item; i < end_item; i++) {
    int idx = i - start_item; 
    int row = idx / icons_per_row;
    int col = idx % icons_per_row;
    int x_pos = 13 + col * 40;
    int y_pos = 14 + row * 24;
    u8g2.drawXBMP(x_pos, y_pos, 16, 16, bitmap_icons[i]);
  }

  u8g2.drawRFrame(highlight_x - 3, highlight_y - 3, 22, 22, 3); 
  u8g2.setDrawColor(0);
  u8g2.drawRFrame(highlight_x - 2, highlight_y - 2, 22, 22, 3); 
  u8g2.setDrawColor(1);

  u8g2.setFont(u8g2_font_5x8_tf); 
  int name_width = u8g2.getUTF8Width(menu_items[item_selected]);
  int name_x = (128 - name_width) / 2;
  u8g2.drawStr(name_x, 64, menu_items[item_selected]); 

  u8g2.drawFrame(124, 18, 4, 38); 
  int bar_height = 38 / total_rows;
  u8g2.drawBox(124, 18 + (bar_height * start_row), 4, bar_height); 

  if (start_row > 0) {
    u8g2.drawStr(124, 15, "."); 
  }
  if (start_row < total_rows - 1) {
    u8g2.drawStr(124, 64, "."); 
  }
  u8g2.sendBuffer();

  setRadiosNeutralState();
}

bool readButton(int pin) {
  if (digitalRead(pin) == LOW && (millis() - last_button_time > DEBOUNCE_DELAY)) {
    last_button_time = millis();
    delay(POST_PRESS_DELAY); 
    return true;
  }
  return false;
}

void setup() {
  Serial.begin(115200);
  neopixelSetup();
  initAllRadios();
  EEPROM.begin(512);
  oledBrightness = EEPROM.read(1);
  u8g2.begin();
  u8g2.setContrast(oledBrightness);
  conf();
  pinMode(BUTTON_UP_PIN, INPUT_PULLUP);
  pinMode(BUTTON_SELECT_PIN, INPUT_PULLUP);
  pinMode(BUTTON_DOWN_PIN, INPUT_PULLUP);
  pinMode(BTN_PIN_RIGHT, INPUT_PULLUP);
  pinMode(BTN_PIN_LEFT, INPUT_PULLUP);
  drawMenu();
}

void loop() {
  if (current_screen == 0) {
    const int icons_per_row = 3;

    if (readButton(BTN_PIN_LEFT)) {
      item_selected = max(0, item_selected - 1);
      drawMenu();
    }
    if (readButton(BTN_PIN_RIGHT)) {
      item_selected = min(NUM_ITEMS - 1, item_selected + 1);
      drawMenu();
    }
    if (readButton(BUTTON_UP_PIN)) {
      item_selected = max(0, item_selected - icons_per_row);
      drawMenu();
    }
    if (readButton(BUTTON_DOWN_PIN)) {
      item_selected = min(NUM_ITEMS - 1, item_selected + icons_per_row);
      drawMenu();
    }
    if (readButton(BUTTON_SELECT_PIN)) {
      current_screen = 1;
      for (int cycle = 0; cycle < 2; cycle++) { 
        for (int i = 0; i < 3; i++) {
          u8g2.clearBuffer();
          u8g2.setFont(u8g2_font_6x10_tr);
          u8g2.drawStr(30, 32, "Loading");
    
          String dots = "";
          for (int j = 0; j <= i; j++) {
            dots += ".";
            setNeoPixelColour("white");
          }
          setNeoPixelColour("0");
          
          u8g2.drawStr(73, 32, dots.c_str()); 
    
          u8g2.sendBuffer();
          delay(200); 
        }
      }
      menu_functions[item_selected]();
      
      while (current_screen == 1) {
        if (menu_loop_functions[item_selected]) {
          menu_loop_functions[item_selected]();
        }
        if (readButton(BUTTON_SELECT_PIN)) {
          current_screen = 0;
          break;
        }
      }
      drawMenu();
    }
  }
}

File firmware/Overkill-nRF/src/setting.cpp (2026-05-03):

/* ____________________________
   This software is licensed under the MIT License:
   https://github.com/cifertech/nrfbox
   ________________________________________ */

#include "setting.h"
#include "icon.h"
#include "config.h"

// Global variable definitions
U8G2_SSD1306_128X64_NONAME_F_HW_I2C u8g2(U8G2_R0, /* reset=*/ U8X8_PIN_NONE);
Adafruit_NeoPixel pixels(1, 14, NEO_GRB + NEO_KHZ800);
bool neoPixelActive = false;
uint8_t oledBrightness = 100;

RF24 RadioA(NRF_CE_PIN_A, NRF_CSN_PIN_A);
RF24 RadioB(NRF_CE_PIN_B, NRF_CSN_PIN_B);
RF24 RadioC(NRF_CE_PIN_C, NRF_CSN_PIN_C);

void setRadiosNeutralState() {
  RadioA.stopListening();
  RadioA.setAutoAck(false);
  RadioA.setRetries(0, 0);
  RadioA.powerDown(); 
  digitalWrite(NRF_CE_PIN_A, LOW); 

  RadioB.stopListening();
  RadioB.setAutoAck(false);
  RadioB.setRetries(0, 0);
  RadioB.powerDown(); 
  digitalWrite(NRF_CE_PIN_B, LOW); 

  RadioC.stopListening();
  RadioC.setAutoAck(false);
  RadioC.setRetries(0, 0);
  RadioC.powerDown(); 
  digitalWrite(NRF_CE_PIN_C, LOW); 
}

void configureNrf(RF24 &radio) {
  radio.begin();
  radio.setAutoAck(false);
  radio.stopListening();
  radio.setRetries(0, 0);
  radio.setPALevel(RF24_PA_MAX, true);
  radio.setDataRate(RF24_2MBPS);
  radio.setCRCLength(RF24_CRC_DISABLED);
}

void setupRadioA() {
  configureNrf(RadioA);
}

void setupRadioB() {
  configureNrf(RadioB);
}

void setupRadioC() {
  configureNrf(RadioC);
}

void initAllRadios() {
  setupRadioA();
  setupRadioB();
  setupRadioC();
}

void Str(uint8_t x, uint8_t y, const uint8_t* asciiArray, size_t len) {
  char buf[64]; 
  for (size_t i = 0; i < len && i < sizeof(buf) - 1; i++) {
    buf[i] = (char)asciiArray[i];
  }
  buf[len] = '\0';

  u8g2.drawStr(x, y, buf);
}

void CenteredStr(uint8_t screenWidth, uint8_t y, const uint8_t* asciiArray, size_t len, const uint8_t* font) {
  char buf[64];
  for (size_t i = 0; i < len && i < sizeof(buf) - 1; i++) {
    buf[i] = (char)asciiArray[i];
  }
  buf[len] = '\0';

  u8g2.setFont((const uint8_t*)font);
  int16_t w = u8g2.getUTF8Width(buf);
  u8g2.setCursor((screenWidth - w) / 2, y);
  u8g2.print(buf);
}

void utils() {
  u8g2.clearBuffer();
  u8g2.setFont(u8g2_font_6x10_tf);
  Str(7, 15, Line_A, sizeof(Line_A));
  Str(12, 35, Line_B, sizeof(Line_B));
  Str(7, 55, Line_C, sizeof(Line_C));
  u8g2.sendBuffer();
}

void conf() {
  u8g2.setBitmapMode(1);
  u8g2.clearBuffer();
  CenteredStr(128, 25, txt_n, sizeof(txt_n), u8g2_font_ncenB14_tr);
  CenteredStr(106, 40, txt_c, sizeof(txt_c), u8g2_font_ncenB08_tr);
  CenteredStr(128, 60, txt_v, sizeof(txt_v), u8g2_font_6x10_tf);
  u8g2.sendBuffer();
  delay(3000);
  u8g2.clearBuffer();
  u8g2.drawXBMP(0, 0, 128, 64, cred); 
  u8g2.sendBuffer();
  delay(250);
}

namespace Setting {

#define EEPROM_ADDRESS_NEOPIXEL 0
#define EEPROM_ADDRESS_BRIGHTNESS 1

int currentOption = 0;
int totalOptions = 3; 

bool buttonUpPressed = false;
bool buttonDownPressed = false;
bool buttonSelectPressed = false;

void updateFirmware() {
  u8g2.clearBuffer();
  u8g2.setFont(u8g2_font_6x10_tf);
  u8g2.drawStr(0, 15, "Updating Firmware.");
  u8g2.sendBuffer();

  u8g2.setFont(u8g2_font_5x8_tr);
  if (!SD.begin(SD_CS_PIN)) {
    u8g2.drawStr(0, 30, "[ SD Init Failed ]");
    u8g2.sendBuffer();
    delay(2000);
    return;
  }

  if (!SD.exists(FIRMWARE_FILE)) {
    u8g2.drawStr(0, 30, "[ File Not Found ]");
    u8g2.sendBuffer();
    delay(2000);
    return;
  }

  File firmware = SD.open(FIRMWARE_FILE);
  if (!firmware) {
    u8g2.drawStr(0, 30, "[ Open Failed ]");
    u8g2.sendBuffer();
    delay(2000);
    return;
  }

  if (firmware) {
    u8g2.drawStr(0, 30, "[ Wait a Moment ]");
    u8g2.sendBuffer();
  }

  if (!Update.begin(firmware.size())) {
    u8g2.drawStr(0, 30, "[ Update Init Failed ]");
    u8g2.sendBuffer();
    firmware.close();
    delay(2000);
    return;
  }

  Update.writeStream(firmware);
  if (Update.end(true)) {
    u8g2.drawStr(0, 45, "[ Update Success! ]");
    u8g2.sendBuffer();
    delay(1000);
    ESP.restart();
  } else {
    u8g2.drawStr(0, 45, "[ Update Failed ]");
    u8g2.sendBuffer();
    delay(2000);
  }

  firmware.close();
}

void toggleOption(int option) {
  if (option == 0) { 
    neoPixelActive = !neoPixelActive;
    EEPROM.write(EEPROM_ADDRESS_NEOPIXEL, neoPixelActive);
    EEPROM.commit();
    Serial.print("NeoPixel is now ");
    Serial.println(neoPixelActive ? "Enabled" : "Disabled");

  } else if (option == 1) { 
    uint8_t brightnessPercent = map(oledBrightness, 0, 255, 0, 100); 
    brightnessPercent += 10; 
    if (brightnessPercent > 100) brightnessPercent = 0; 
    oledBrightness = map(brightnessPercent, 0, 100, 0, 255); 

    u8g2.setContrast(oledBrightness); 
    EEPROM.write(EEPROM_ADDRESS_BRIGHTNESS, oledBrightness);
    EEPROM.commit();

    Serial.print("Brightness set to: ");
    Serial.print(brightnessPercent);
    Serial.println("%");

  } else if (option == 2) {
    updateFirmware();
  }
}
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

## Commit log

2026-04-19 add images and remove files
    [Overkill-nRF.kicad_pcb, nrf24l01.kicad_sch, oled.kicad_sch]
2026-04-19 add cad
2026-04-19 add firmware and bom
    [lcsc.csv]
2026-04-19 align bom csv
    [lcsc.csv]
2026-04-19 move to bom file
    [aliexpress.csv, lcsc.csv]
2026-04-19 update bom
    [aliexpress.csv, lcsc.csv]
2026-04-19 add freecad
    [Overkill-nRF.FCStd]
2026-04-19 update boms
    [aliexpress.csv, lcsc.csv]
2026-04-19 align bom
    [aliexpress.csv]
2026-04-19 remove test
    [aliexpress.csv]
2026-04-19 update cost
    [aliexpress.csv, lcsc.csv]
2026-04-19 add bom
    [bom.csv]
2026-04-20 remove unnecessary bom
    [aliexpress.csv, bom.csv, lcsc.csv]
2026-04-20 fix bom
    [bom.csv]
2026-04-20 test bom files
2026-04-20 update bom section
2026-04-20 move bom
    [bom.csv]
2026-04-20 bom try again
    [bom.csv]
2026-04-20 add assembly
2026-05-03 update firmware
    [Overkill-nRF.kicad_pcb]
